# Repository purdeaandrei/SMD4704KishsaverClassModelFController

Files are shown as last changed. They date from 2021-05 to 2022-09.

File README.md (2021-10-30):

# SMD Model F controller based on TH Xwhatsit design. ('kishsaver' variant)

This variant is for IBM 4704 keyboards, aka 'kishsaver' class model F keyboards, like F107, F50, F62, F77
This variant is not 100% compatible with the https://www.modelfkeyboards.com/ recreations of the F62/F77, because the pin pitch is different,
although it is electrically compatible with those too, if one decides to wire it up with individual wires.

For other variants see:
* https://github.com/purdeaandrei/SMDModelFController/tree/extra_columns
* https://github.com/purdeaandrei/SMDModelFController
* https://github.com/listofoptions/TH-XWhatsIt

## Images

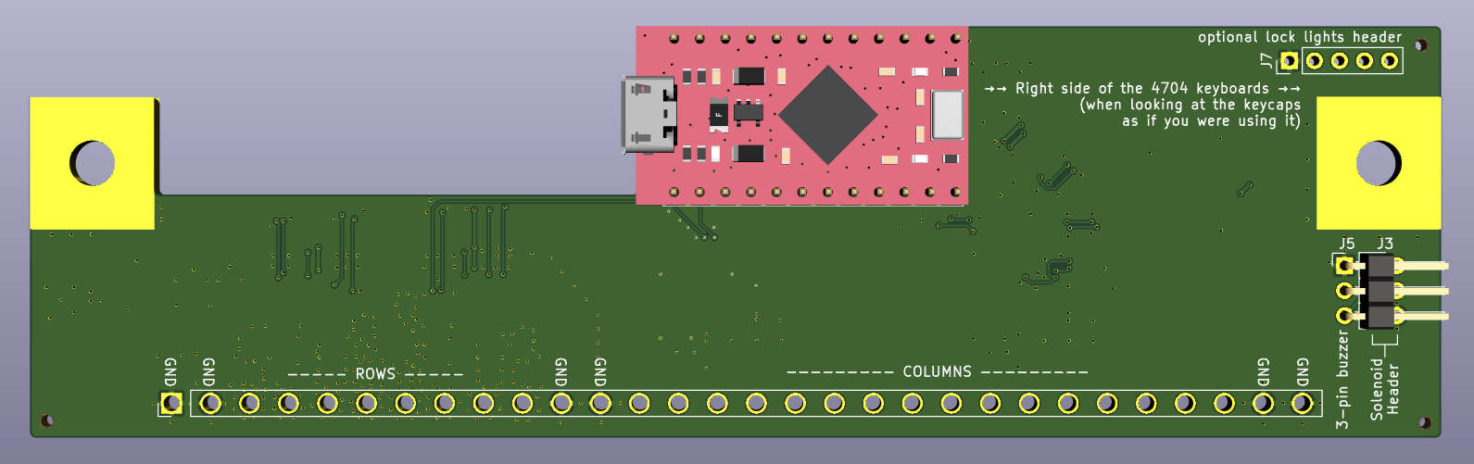
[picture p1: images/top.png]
Top of the controller board

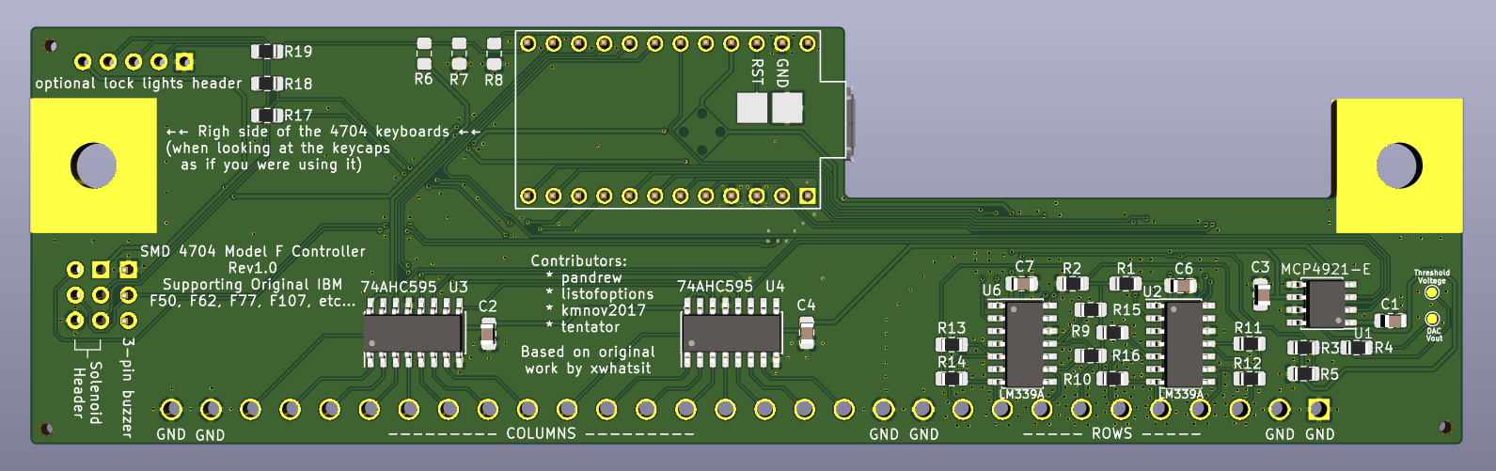
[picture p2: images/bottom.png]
Bottom of the controller board


## Origins and license

This project is based on the Through-hole xwhatsit by listofoptions, which is un turn
based on the capsense controllers by XWhatsIt
(Tom Wong-Cornall). original liscencure holds, as well as CERN OSH
(compatible license).

original implementation of Tom Wong-Cornall's controller documented here

http://downloads.cornall.co/ibm-capsense-usb-web/ibm-capsense-usb.html

Working theory of operation is under the previous link.

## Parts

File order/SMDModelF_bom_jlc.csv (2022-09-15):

Comment | Designator | Footprint | LCSC Part #
0U1 | C2,C3,C1,C4,C7,C6 | C_0805_2012Metric_Pad1.15x1.40mm_HandSolder | C49678
1K | R2 | R_0805_2012Metric_Pad1.15x1.40mm_HandSolder | C17513
20K | R4,R3 | R_0805_2012Metric_Pad1.15x1.40mm_HandSolder | C4328
4K7 | R5,R1 | R_0805_2012Metric_Pad1.15x1.40mm_HandSolder | C17673
100k 1% | R9,R10,R11,R12,R13,R14,R15,R16 | R_0805_2012Metric_Pad1.15x1.40mm_HandSolder | C149504
330 | R17,R19,R18 | R_0805_2012Metric_Pad1.15x1.40mm_HandSolder | C17630
MCP4921-E | U1 | SOIC-8_3.9x4.9mm_P1.27mm | C43499
LM339A | U2,U6 | SOIC-14_3.9x8.7mm_P1.27mm | C74559
74AHC595 | U3,U4 | SOIC-16_3.9x9.9mm_P1.27mm | C5520

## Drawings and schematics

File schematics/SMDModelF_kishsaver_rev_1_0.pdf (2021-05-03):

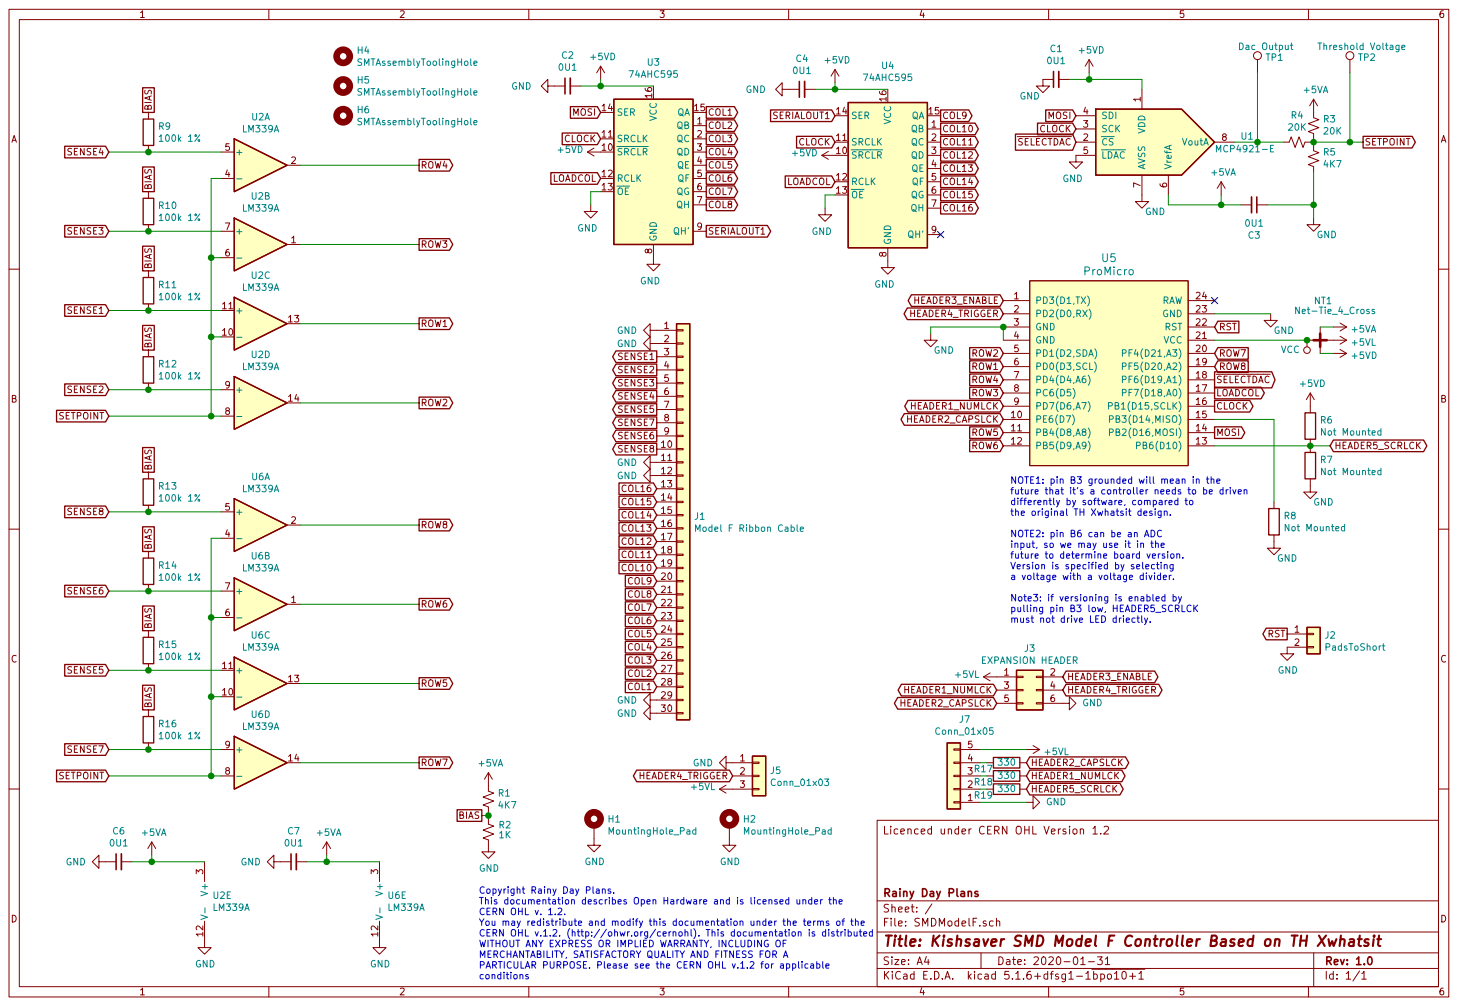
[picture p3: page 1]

+5VL GND GND GND GND GND

NOTE1: pin B3 grounded will mean in the
future that it's a controller needs to be driven
differently by software, compared to
the original TH Xwhatsit design.

NOTE2: pin B6 can be an ADC
input, so we may use it in the
future to determine board version. Version is specified by selecting

a voltage with a voltage divider.

Note3: if versioning is enabled by
pulling pin B3 low, HEADER5_SCRLCK
must not drive LED driectly.

Licenced under CERN OHL Version 1.2

Copyright Rainy Day Plans.
This documentation describes Open Hardware and is licensed under the CERN OHL v. 1.2. You may redistribute and modify this documentation under the terms of the

Id: 1/1 Title: Kishsaver SMD Model F Controller Based on TH Xwhatsit File: SMDModelF.sch Sheet: / Rainy Day Plans

CERN OHL v.1.2. (http://ohwr.org/cernohl). This documentation is distributed WITHOUT ANY EXPRESS OR IMPLIED WARRANTY, INCLUDING OF MERCHANTABILITY, SATISFACTORY QUALITY AND FITNESS FOR A

PARTICULAR PURPOSE. Please see the CERN OHL v.1.2 for applicable
conditions

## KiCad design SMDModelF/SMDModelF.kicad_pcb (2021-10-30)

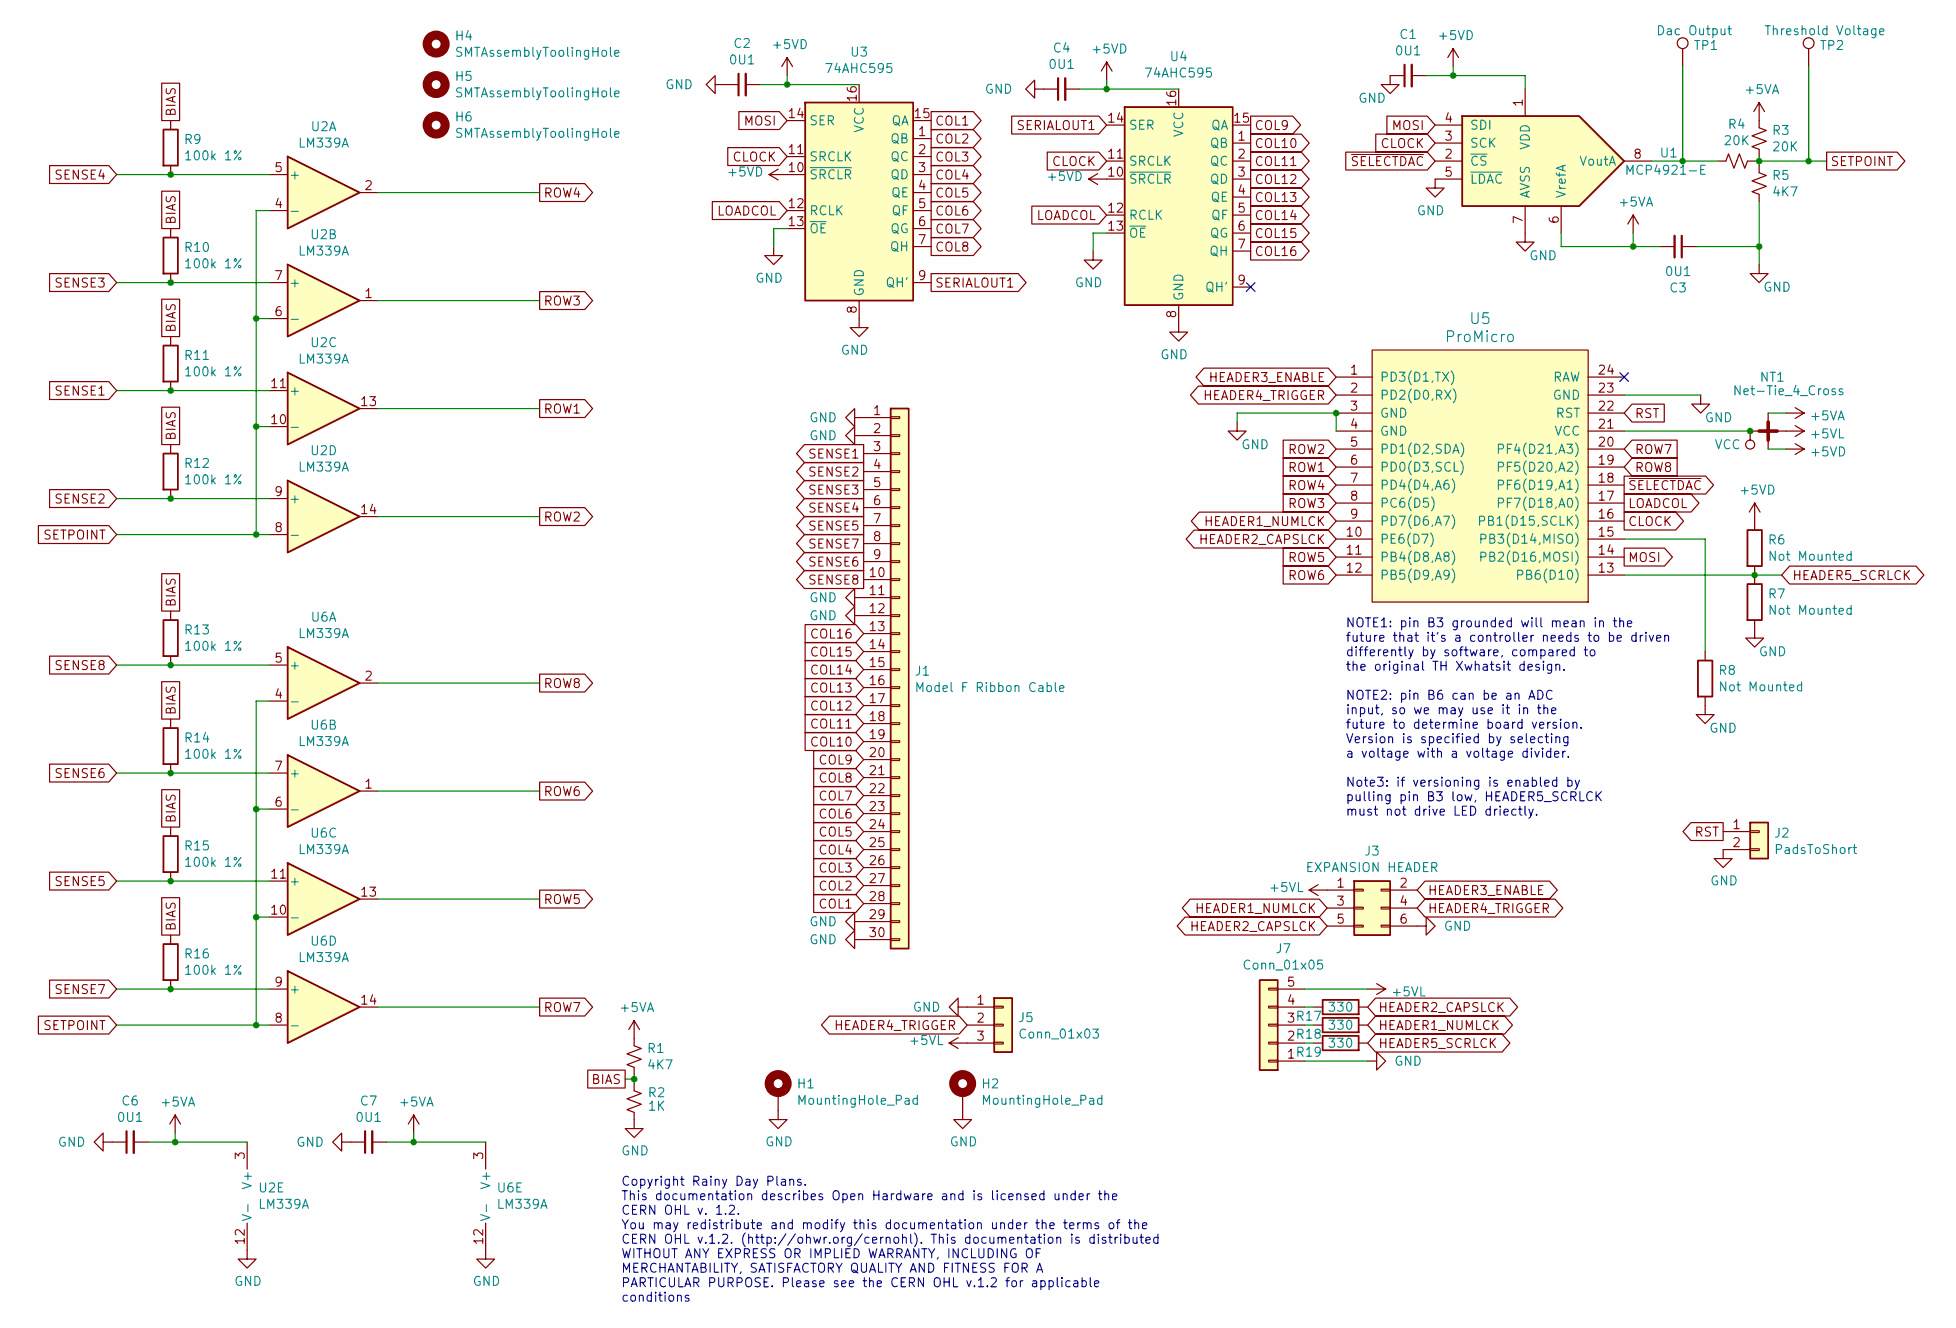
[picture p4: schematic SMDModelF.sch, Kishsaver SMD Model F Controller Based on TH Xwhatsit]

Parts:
C1, C2, C3, C4, C6, C7: 0U1; C_0805_2012Metric_Pad1.15x1.40mm_HandSolder; LCSC C49678
H1, H2: MountingHole_Pad; kishsaver_mounting_hole
H4, H5, H6: SMTAssemblyToolingHole; tooling_hole
J1: Model F Ribbon Cable; Model_F_3.96mm_pitch_footprint
J2: PadsToShort
J3: EXPANSION HEADER; SolenoidPinheaderNoCourtyard
J5: Conn_01x03; PinHeader_1x03_P2.54mm_Horizontal
J7: Conn_01x05; PinHeader_1x05_P2.54mm_Vertical_no3d
NT1: Net-Tie_4_Cross; NetTie-4_THT_Pad1.0mm
R1, R5: 4K7; R_0805_2012Metric_Pad1.15x1.40mm_HandSolder; LCSC C17673
R2: 1K; R_0805_2012Metric_Pad1.15x1.40mm_HandSolder; LCSC C17513
R3, R4: 20K; R_0805_2012Metric_Pad1.15x1.40mm_HandSolder; LCSC C4328
R6, R7, R8: Not Mounted; R_0805_2012Metric_Pad1.15x1.40mm_HandSolder
R9, R10, R11, R12, R13, R14, R15, R16: 100k 1%; R_0805_2012Metric_Pad1.15x1.40mm_HandSolder; LCSC C17407
R17, R18, R19: 330; R_0805_2012Metric_Pad1.15x1.40mm_HandSolder; LCSC C17630
TP1: Dac Output; TestPoint_Pad_D1.0mm
TP2: Threshold Voltage; TestPoint_Pad_D1.0mm
U1: MCP4921-E; SOIC-8_3.9x4.9mm_P1.27mm; LCSC C43499
U2, U6: LM339A; SOIC-14_3.9x8.7mm_P1.27mm; LCSC C74559
U3, U4: 74AHC595; SOIC-16_3.9x9.9mm_P1.27mm; LCSC C5520
U5: ProMicro

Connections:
+5VA: C3.2, C6.2, C7.2, NT1.3, R1.1, R3.2, U1.6 (VrefA), U2.3 (V+), U6.3 (V+)
+5VD: C1.2, C2.2, C4.2, NT1.4, R6.1, U1.1 (VDD), U3.10 (~SRCLR), U3.16 (VCC), U4.10 (~SRCLR), U4.16 (VCC)
+5VL: J3.1, J5.3, J7.5, NT1.2
BIAS: R1.2, R2.2, R9.1, R10.1, R11.1, R12.1, R13.1, R14.1, R15.1, R16.1
CLOCK: U1.3 (SCK), U3.11 (SRCLK), U4.11 (SRCLK), U5.16 (PB1(D15,SCLK))
COL1: J1.28, U3.15 (QA)
COL2: J1.27, U3.1 (QB)
COL3: J1.26, U3.2 (QC)
COL4: J1.25, U3.3 (QD)
COL5: J1.24, U3.4 (QE)
COL6: J1.23, U3.5 (QF)
COL7: J1.22, U3.6 (QG)
COL8: J1.21, U3.7 (QH)
COL9: J1.20, U4.15 (QA)
COL10: J1.19, U4.1 (QB)
COL11: J1.18, U4.2 (QC)
COL12: J1.17, U4.3 (QD)
COL13: J1.16, U4.4 (QE)
COL14: J1.15, U4.5 (QF)
COL15: J1.14, U4.6 (QG)
COL16: J1.13, U4.7 (QH)
GND: C1.1, C2.1, C3.1, C4.1, C6.1, C7.1, H1.1, H2.1, J1.1, J1.2, J1.11, J1.12, J1.29, J1.30, J2.2, J3.6, J5.1, J7.1, R2.1, R5.1, R7.2, R8.2, U1.5 (~LDAC~), U1.7 (AVSS), U2.12 (V-), U3.8 (GND), U3.13 (~OE), U4.8 (GND), U4.13 (~OE), U5.3 (GND), U5.4 (GND), U5.23 (GND), U6.12 (V-)
HEADER1_NUMLCK: J3.3, R18.2, U5.9 (PD7(D6,A7))
HEADER2_CAPSLCK: J3.5, R17.2, U5.10 (PE6(D7))
HEADER3_ENABLE: J3.2, U5.1 (PD3(D1,TX))
HEADER4_TRIGGER: J3.4, J5.2, U5.2 (PD2(D0,RX))
HEADER5_SCRLCK: R6.2, R7.1, R19.2, U5.13 (PB6(D10))
LOADCOL: U3.12 (RCLK), U4.12 (RCLK), U5.17 (PF7(D18,A0))
MOSI: U1.4 (SDI), U3.14 (SER), U5.14 (PB2(D16,MOSI))
unnamed: J7.2, R19.1
unnamed: J7.3, R18.1
unnamed: J7.4, R17.1
unnamed: R4.2, TP1.1, U1.8 (VoutA)
unnamed: R8.1, U5.15 (PB3(D14,MISO))
ROW1: U2.13, U5.6 (PD0(D3,SCL))
ROW2: U2.14, U5.5 (PD1(D2,SDA))
ROW3: U2.1, U5.8 (PC6(D5))
ROW4: U2.2, U5.7 (PD4(D4,A6))
ROW5: U5.11 (PB4(D8,A8)), U6.13
ROW6: U5.12 (PB5(D9,A9)), U6.1
ROW7: U5.20 (PF4(D21,A3)), U6.14
ROW8: U5.19 (PF5(D20,A2)), U6.2
RST: J2.1, U5.22 (RST)
SENSE1: J1.3, R11.2, U2.11 (+)
SENSE2: J1.4, R12.2, U2.9 (+)
SENSE3: J1.5, R10.2, U2.7 (+)
SENSE4: J1.6, R9.2, U2.5 (+)
SENSE5: J1.7, R15.2, U6.11 (+)
SENSE6: J1.9, R14.2, U6.7 (+)
SENSE7: J1.8, R16.2, U6.9 (+)
SENSE8: J1.10, R13.2, U6.5 (+)
SERIALOUT1: U3.9 (QH'), U4.14 (SER)
SETPOINT: R3.1, R4.1, R5.2, TP2.1, U2.4 (-), U2.6 (-), U2.8 (-), U2.10 (-), U6.4 (-), U6.6 (-), U6.8 (-), U6.10 (-)
VCC: NT1.1, U5.21 (VCC)
~SELECTDAC: U1.2 (~CS~), U5.18 (PF6(D19,A1))

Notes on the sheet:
Copyright Rainy Day Plans. This documentation describes Open Hardware and is licensed under the CERN OHL v. 1.2. You may redistribute and modify this documentation under the terms of the CERN OHL v.1.2. (http://ohwr.org/cernohl). This documentation is distributed WITHOUT ANY EXPRESS OR IMPLIED WARR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
NOTE1: pin B3 grounded will mean in the future that it's a controller needs to be driven differently by software, compared to the original TH Xwhatsit design. NOTE2: pin B6 can be an ADC input, so we may use it in the future to determine board version. Version is specified by selecting a voltage wi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

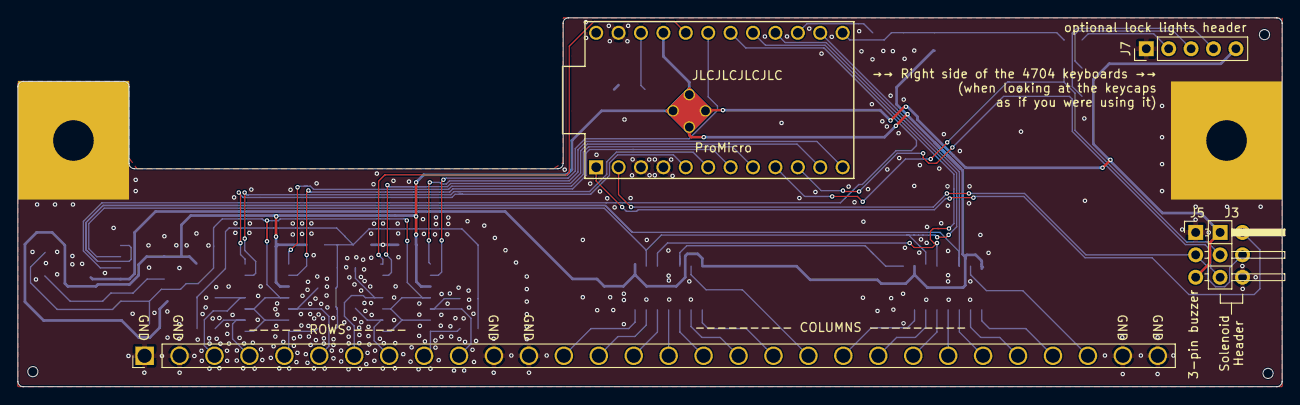
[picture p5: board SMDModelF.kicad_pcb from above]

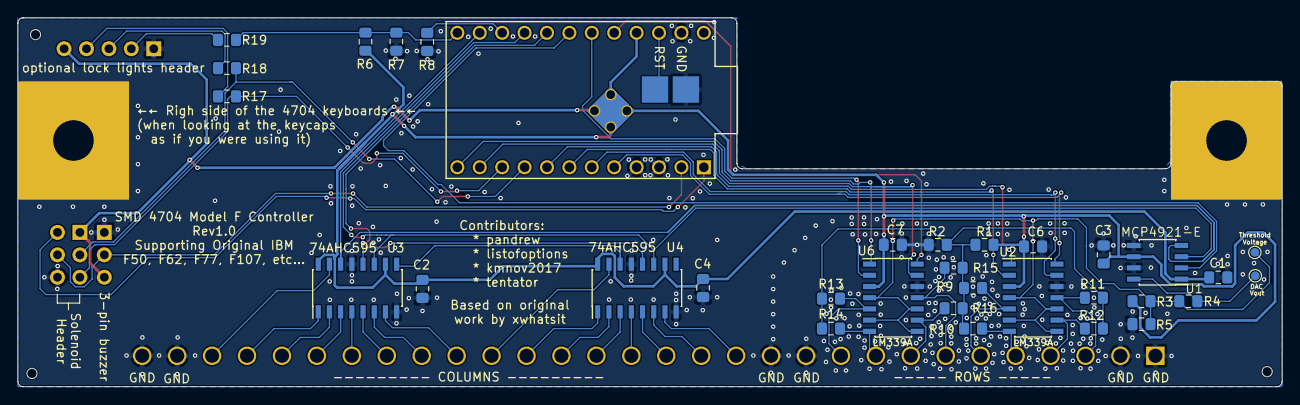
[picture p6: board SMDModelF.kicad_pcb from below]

Board: 2 copper layers, 143.3 x 41.8 mm, 44 parts (33 on the bottom side), 55 nets.

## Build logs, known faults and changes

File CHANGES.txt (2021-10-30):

January 31St, 2020:
    user: Listofoptions
        done:
            initial commit, completed main controller board and schematic
        todo:
            plugboard wiring and socket / connector positioning
            physical hardware testing
            firmware 
            firmware testing

Febuary 3rd, 2020
    user: Listofoptions
        done:
            moved setpoint decoupler cap to hopefully lower interferance with
            relatively high frequency output from the comparitors
            
            connector positioning for plugboard complete
            
            moved sense connector to allow better placement of corresponding
            socket on plugboards (sense traces needed more room on plugboards)
        todo:
            displaywriter plugboard wiring
            physical hardware testing
            firmware
            firmware testing
Febuary 4th, 2020
    user: listofoptions
        done:
            added ground strap points to plugboards, and positioned them to
            align with the ground strap on the main board
            
            displaywriter plugboard completely wired
            
            added cutouts in plugboards for expasion header wiring
        todo:
            maybe add more grounding straps to aid in mechanical strength
            (i intend to use metal standoffs to connect the plugboards and 
            main board)
            
            physical hardware testing
            firmware
            firmware testing
August 14th, 2020
    user: listofoptions
        done:
            complete smd rework 
        todo:
            fine tune the castelations
            add cutouts for throughhole components to pigybacking plugboards
            rewire and resize plugboards for max compatibility
            physical hardware testing
            firmware
            firmware testing
Unknown date
    user: purdeaandrei
        done:
            Converted to SMD, sized for 'standard' Model F keyboards.
Unknown date
    user: purdeaandrei
        done:
            Re-arranged pcb to make it 'kishsaver-class' compatible
May 3 2021:
    user: purdeaandrei
        done:
            Updated Pro Micro schematic symbol (fixed incorrect pin names, and made pin names more verbose)
            Added schematics in PDF form.
Oct 30, 2021
    user: purdeaandrei
        done:
            Removed datasheets
            Updated some licensing info
            Mark some components that are not supposed to be mounted virtual, for more correct 3d rendering.
            Added images, tweaked readme.

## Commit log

2020-09-30 First version of kishsaver-class model F controller
    [CompactBeamspring.kicad_pcb, CompactBeamspring.sch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]
2020-12-13 Pro Micro footprint: updated to include 3d models by default.
2020-12-13 Added footprints for no-3d solenoid header, and with 3d for beeper header
    [SMDModelF.sch]
2020-12-13 PCB file: updated footprints and references to 3d parts.
    [SMDModelF.kicad_pcb]
2021-05-03 Updated pro micro schematic symbol, and added PDF schematics
    [SMDModelF.sch]
2021-10-30 Clarified license of the footprint library
2021-10-30 Mark some components virtual, add images, tweak readme
    [SMDModelF.kicad_pcb]
2022-02-14 Update component rotations, to match new behaviour of JLCPCB on the bottom layer
    [SMDModelF_cpl_jlc.csv]
2022-07-31 Updated 100k resistor and shift register LCSC part numbers
    [SMDModelF.sch, SMDModelF_bom_jlc.csv]
2022-07-31 fix rotations to match latest JLCPCB behaviour
    [SMDModelF_cpl_jlc.csv]
2022-09-15 Revert part of commit 'Updated 100k resistor and shift register LCSC part numbers' (the shift register BOM changes only)
    [SMDModelF.sch, SMDModelF_bom_jlc.csv]
